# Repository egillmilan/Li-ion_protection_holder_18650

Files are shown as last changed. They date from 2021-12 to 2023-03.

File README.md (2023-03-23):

# Li-ion protection holder
A protection circuit for a single 18650 lithium-ion cell. The circuit protects the battery from over-voltage (4.225V), under-voltage (3.2V), over-current discharge (~5A) and over-current charging (~5A). The protection thresholds depend on the choice of MOSFETs and the version of the AP9101C protection IC that is being used.

The device also acts as a battery holder for easy integration into various projects. The pin header holes are spaced 2.54mm apart which enables the holder to be soldered onto common perforated prototyping boards or it can even be plugged into breadboards.

Li-ion_18650_holder
Li-ion_18650_holder2

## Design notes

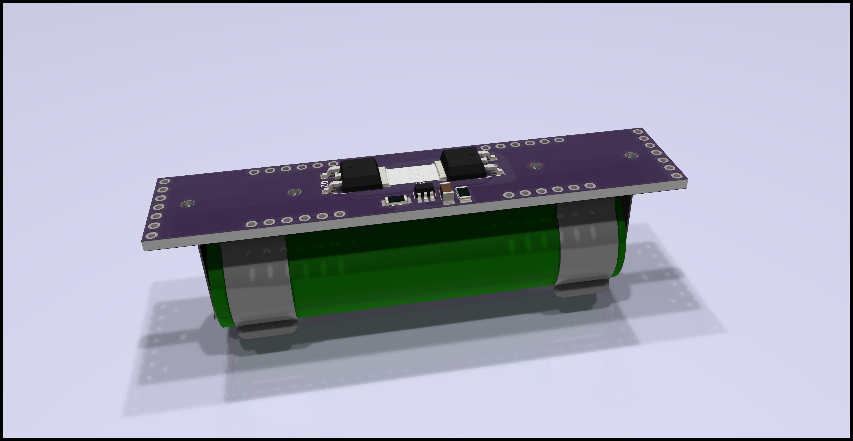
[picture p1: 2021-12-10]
Li-ion_18650_holder/Li-ion_18650_holder2.png

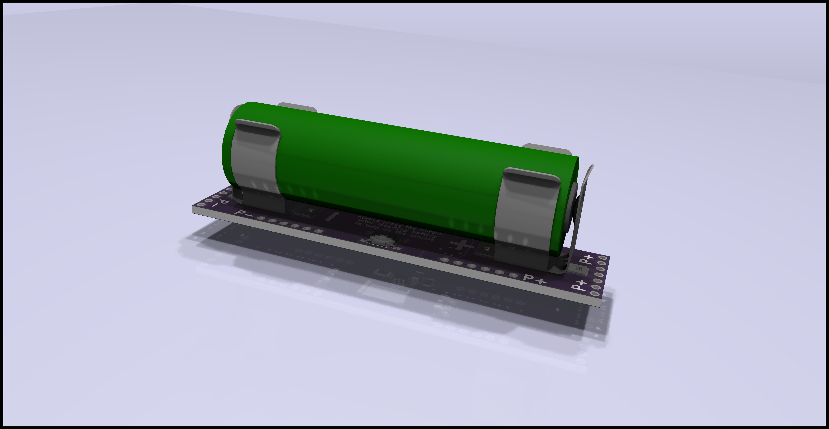
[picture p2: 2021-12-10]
Li-ion_18650_holder/Li-ion_18650_holder.png

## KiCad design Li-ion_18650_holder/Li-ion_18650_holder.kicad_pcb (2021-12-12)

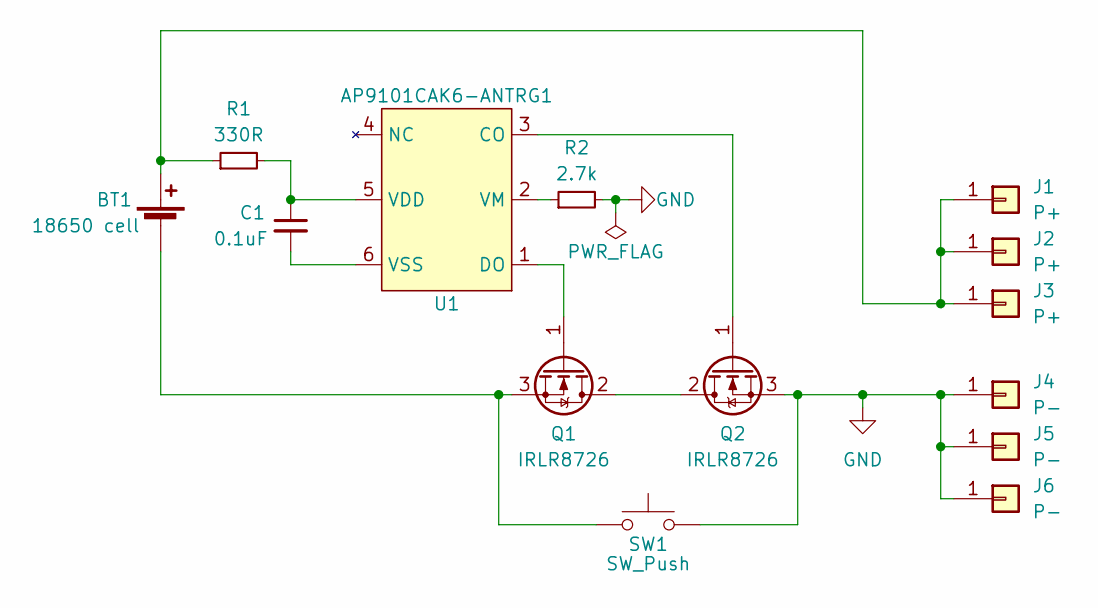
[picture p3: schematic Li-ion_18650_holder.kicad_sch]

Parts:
BT1: 18650 cell; Keystone_254_holder
C1: 0.1uF; C_1206_3216Metric_Pad1.33x1.80mm_HandSolder
J1, J3: P+; PinSocket_1x06_P2.54mm_Vertical
J2: P+; PinSocket_1x07_P2.54mm_Vertical
J4, J6: P-; PinSocket_1x06_P2.54mm_Vertical
J5: P-; PinSocket_1x07_P2.54mm_Vertical
Q1, Q2: IRLR8726; TO-252-2
R1: 330R; R_1206_3216Metric_Pad1.30x1.75mm_HandSolder
R2: 2.7k; R_1206_3216Metric_Pad1.30x1.75mm_HandSolder
SW1: SW_Push; TL3342F260QG
U1: AP9101CAK6-ANTRG1; SOT-23-6_Handsoldering

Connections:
GND: J4.1, J5.1, J6.1, Q2.3 (S), R2.2, SW1.2
unnamed: BT1.1 (+), J1.1, J2.1, J3.1, R1.1
unnamed: BT1.2 (-), Q1.3 (S), SW1.1
unnamed: C1.1, R1.2, U1.5 (VDD)
unnamed: C1.2, U1.6 (VSS)
unnamed: Q1.1 (G), U1.1 (DO)
unnamed: Q1.2 (D), Q2.2 (D)
unnamed: Q2.1 (G), U1.3 (CO)
unnamed: R2.1, U1.2 (VM)

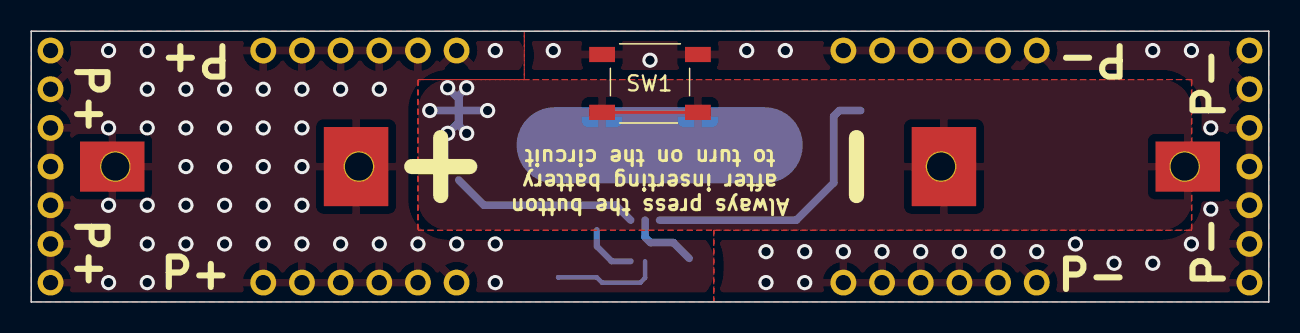
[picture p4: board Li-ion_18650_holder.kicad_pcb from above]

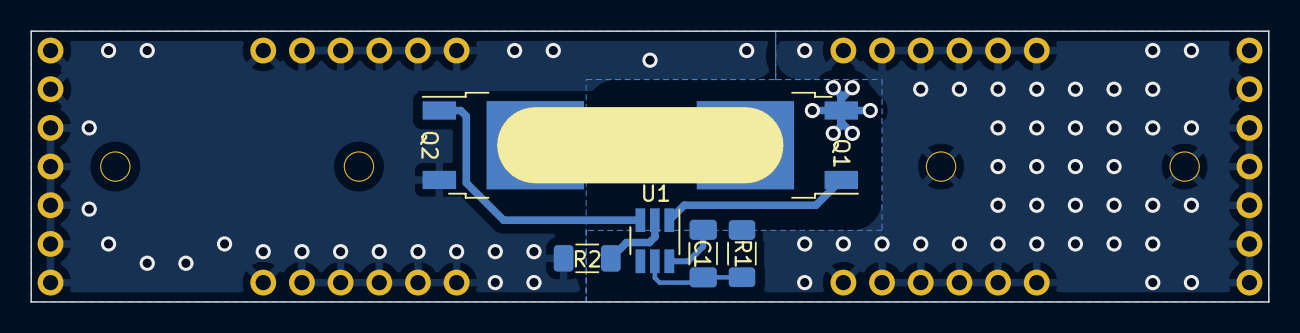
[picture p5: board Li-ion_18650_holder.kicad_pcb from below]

Board: 2 copper layers, 81.3 x 17.8 mm, 14 parts (12 on the bottom side), 9 nets.
